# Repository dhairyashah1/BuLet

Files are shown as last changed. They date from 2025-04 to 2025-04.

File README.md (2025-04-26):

# BuLET: An Ultra Low Energy Transmitter

This repository contains the code and artifacts for **BuLet** which is developed as a part of CS5272: Embedded Software Design Course Project, Spring 2025 held at NUS.

> The BuLET system aims to enable low-power BLE
advertisement transmissions in the 1M / 2M PHY modes with
the provision of Extended PHY later. These transmissions are
decodable by commodity BLE receivers like smartphones:

<div align="center">
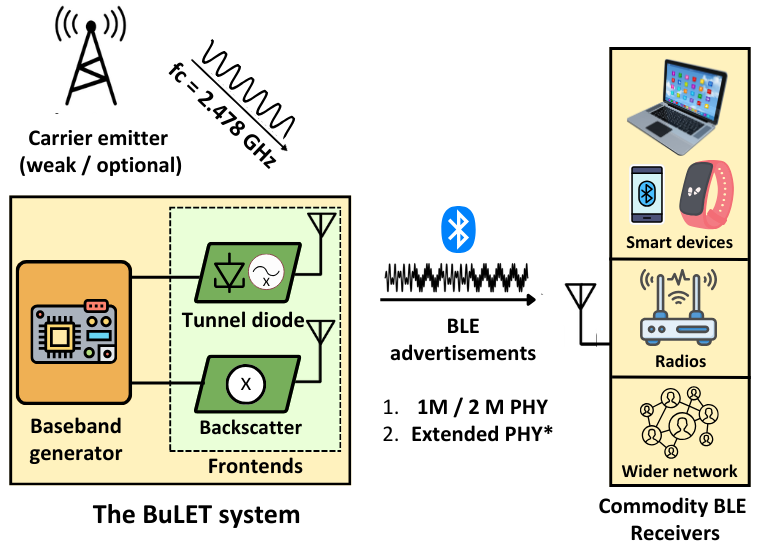
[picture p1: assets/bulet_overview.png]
BuLET Overview

</div>

## Abstract

Increased embedded system deployments have driven the widespread adoption of various wireless standards. Commonly used protocols include Wi-Fi, Bluetooth, ZigBee, and LoRa operate in the Industrial, Scientific and Medical bands (ISM) i.e. 868 MHz and 2.4 GHz showing their ubiquity and allowance for unlicensed transmissions. Despite advancements in low-power sensors and microcontrollers, the wireless radio subsystem—particularly its analog front end—remains a major power bottleneck in embedded IoT devices. Classic Bluetooth and Bluetooth Low Energy (BLE) dominate short-range wireless communication in the 2.4 GHz spectrum, with BLE favored for its energy efficiency in lightweight, battery-powered applications. However, even state-of-the-art BLE transmitters typically consume around 20 mW  to hundreds to milliwatts, limiting lifetime for battery-operated devices. Existing low-power solutions, such as BLE backscatter, decrease transmission power but rely on external emitters to generate carrier signals, which incurs additional energy costs. Tunnel diode oscillators present another option for generating radio signals with power consumption below 100 µW but face stability issues. In this work, we introduce BuLET, an ultra-low-power Bluetooth transmitter that integrate both backscatter and tunnel diode oscillator (TDO)-based frontends with a commercial microcontroller to generate BLE-compliant advertisements for unidirectional communication. We also demonstrate sub-harmonic injection locking to stabilize the TDO for reliable communication.

## Contributions

1.  BuLET is a compact (10cm x 5cm) system built using off-the-shelf components. It houses a low-power microcontroller for baseband generation and processing combining both **tunnel diode** based and **backscatter** frontends. This enables energy-efficient unidirectional BLE advertisments}= for sustainable communication.
2. Extending on Judo architecture, BuLET stabilizes the TDO from resonant frequency shifts by injection-locking lower-frequency sub-harmonic of TDO at **1.239 GHz** (**sub-harmonic injection locking**, min strength = 50 dBm). This supports the argument that lower-frequency signals are easier to generate from commodity devices. 
3. BuLET has a total power consumption of under **250 µW** which includes the baseband generator and frontends.
4. BuLET's transmissions are compatible to be received by commodity BLE receivers like smartphones and tablets.

## Repository Organization

```
├── LICENSE
├── README.md
├── assets                     # pictures, plots and images
│   ├── backscatter_frontend
│   ├── baseband_generator
│   └── tdo_frontend
├── data_logs                  # spectrum analyzer data
│   ├── cabled_spectrum
│   └── wireless_spectrum
├── examples
├── firmware                   # firmware implementations for BLE baseband
│   ├── beaglebone             # (1) beaglebone black implementation using PRU
│   └── ble_baseband_5969      # (2) msp430 implementation 
└── hardware                   # hardware PCB design files for BuLET designed in eagle
    ├── README.md             
    ├── backscatter_frontend
    ├── baseband_generator
    └── tdo_frontend
```

## Hardware Design

### Platform and Baseband Generator

The hardware platform prototype of the BuLET
system consists of a baseband generator and both backscatter
and tunnel diode based frontends to support low-power BLE
transmissions.

<div align="center">
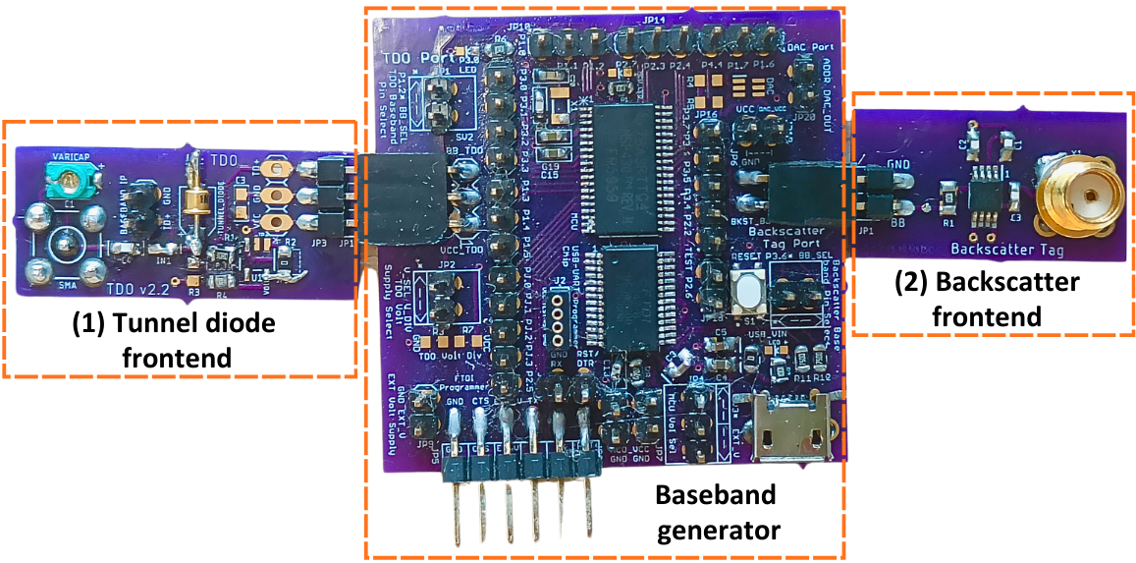
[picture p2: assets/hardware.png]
BuLET Hardware

</div>

### Tunnel Diode Oscillator Frontend

A tunnel diode oscillator built using a 1N3712 tunnel diode and passive RLC components. It oscillates at the following frequencies measured in a cabled setup.
- Principal frequency = 1.23 GHz, -26 dBm
- Second harmonic frequency = 2.47 GHz, -45 dBm

<div align="center">
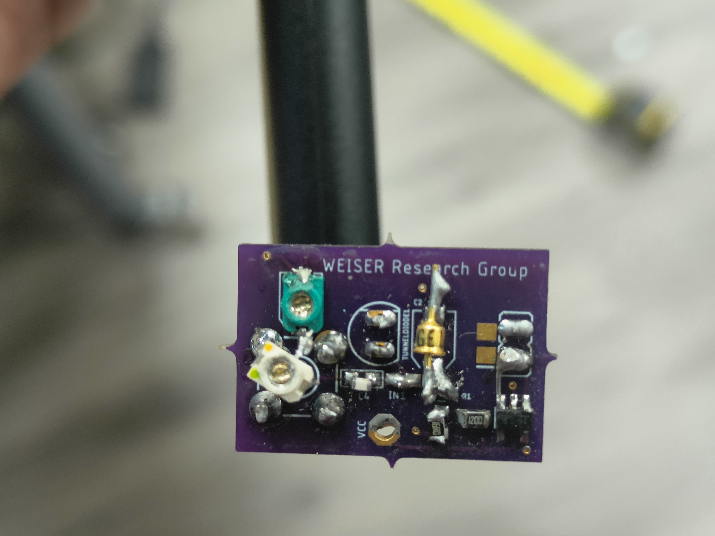
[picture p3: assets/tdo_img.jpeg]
TDO

</div>

Spectrum of unmodulated carrier signals generated by TDO captured in a cabled setup.

<div align="center">
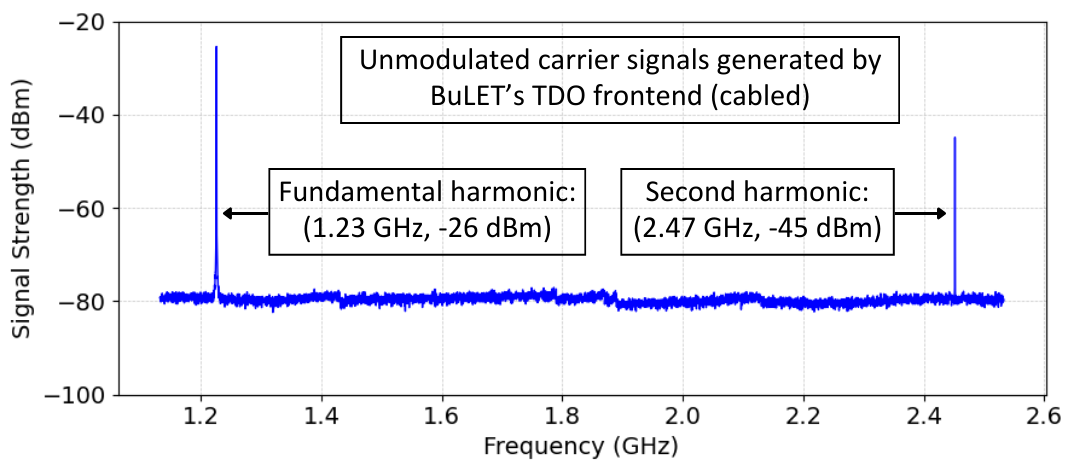
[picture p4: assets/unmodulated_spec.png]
Unmodulated spectrum of TDO

</div>

Spectrum of the modulated / mixed signal after sub-harmonic injection locking captured in a wireless setup. The carrier signals generated by TDO, after mixing with the BLE baseband signal represents the mixed signal. The lower-order or principal harmonic at 1.23 GHz is injection locked, which also stabilizes the second harmonic at 2.47 GHz. Minimum injection locking strength is reported to be as -50 dBm.

<div align="center">
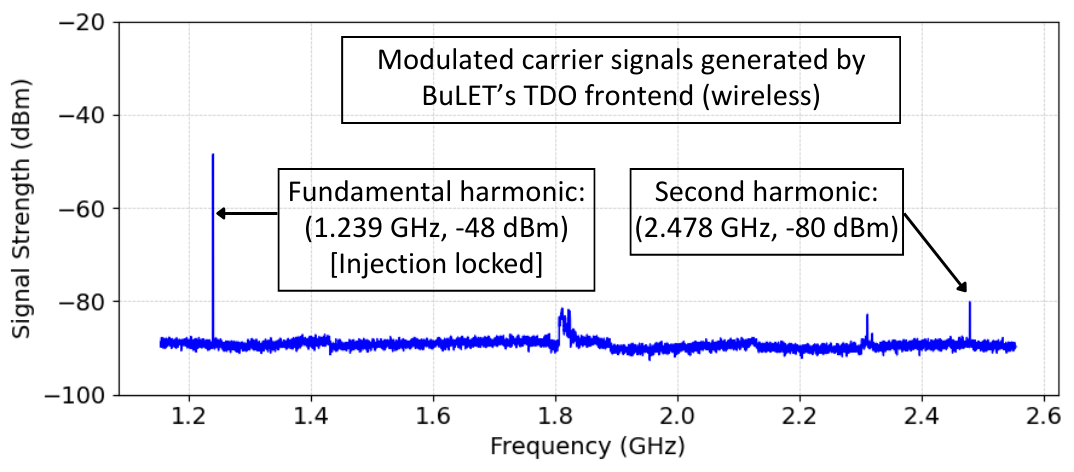
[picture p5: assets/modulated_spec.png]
Modulated spectrum of TDO

</div>

# Evaluation

### Evaluation Setup
<div align="center">
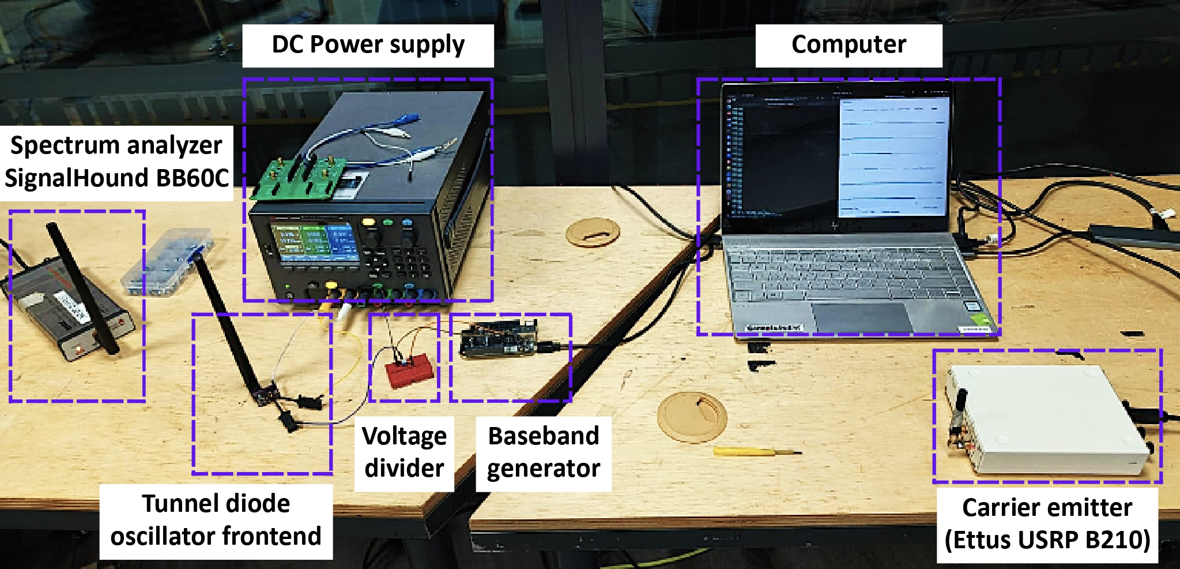
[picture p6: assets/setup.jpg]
Evaluation SEtup

</div>

### Backscatter Frontend

Signal strength of the BLE advertisements (mixed signal) recorded on a spectrum analyzer at various distances in a LoS setting with changing distances between the carrier emitter and the tag: 0.5 m, 1 m, 1.5 m, 2 m.

<div align="center">
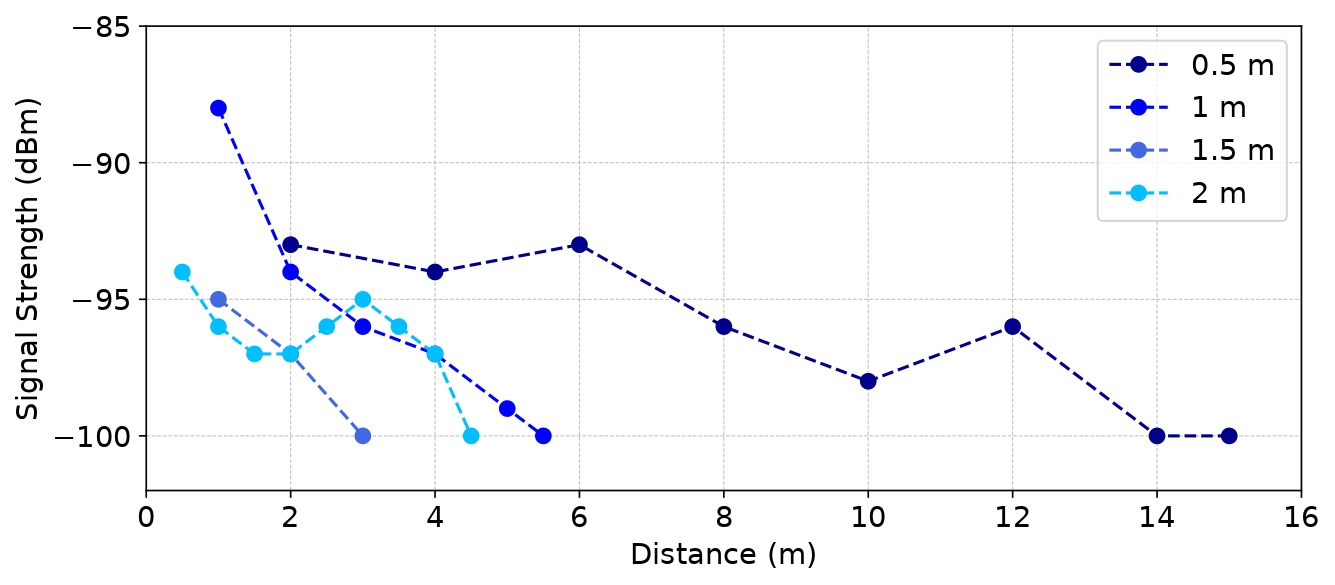
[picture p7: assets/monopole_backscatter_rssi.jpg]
Backscatter Evaluation

</div>

### Performance Comparison of Frontends

TDO frontend achieves a minimal range of 1 m as compared to 5.5 m by backscatter when the carrier emitter / injection locking device are kept each 1.5 m away from the tag. This is due to the weak carrier signal generated by TDO and even weaker mixed signal at 2.478 GHz (39th Advertisement channel).

<div align="center">
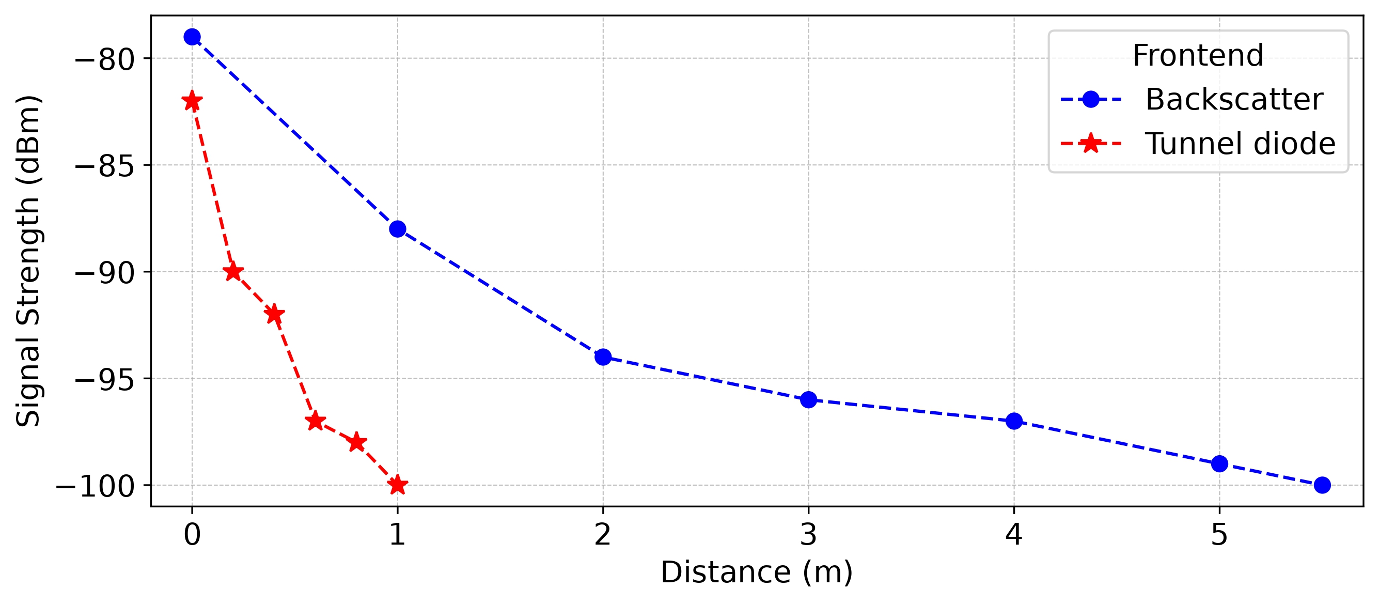
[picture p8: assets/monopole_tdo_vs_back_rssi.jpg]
Comparative Evaluation

</div>

### Reception

Successful reception of BuLET generated BLE advertisements from either frontends on a capable commodity smartphone.

<div align="center">
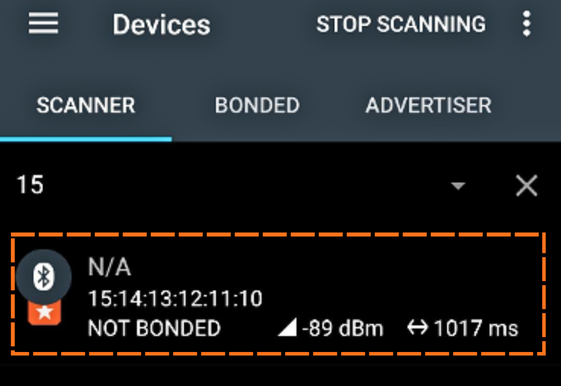
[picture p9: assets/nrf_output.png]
Output on smartphone

</div>

### Power consumption 

Comparison of power consumption and lifetime of BuLET with different wireless technologies on a 225 mAh CR2032 battery.

| **Technology** | **Power Consumption** | **Lifetime (225 mAh battery)** |
|:---|:---:|:---:|
| **Active Classic Bluetooth TX**  | 0.5 - 1 W | 40 minutes |
| **Active BLE TX** | 20 - 100 mW | 15 hours |
| **BuLET Backscatter TX** | 150 μW | 80 - 100 days |
| **BuLET Tunnel diode TX** | 250 μW | 50 - 80 days |

## Limitations

- Early prototype of a low-power BLE transmitter using tunnel diode oscillators (TDO) and sub-harmonic injection locking.
- Current TDO is unable to:
  - Generate stronger signal strength at the second harmonic. OR
  - Build a TDO operating with principal harmonic at 2.478 GHz.
- These limitations affect system performance and the ability to use weaker injection locking signals.
- Achieving this would establish significant novelty over existing backscatter systems.

## Future Work
- Build a 2.4 GHz TDO with a strong principal harmonic.
- Enable various BLE modes, including:
  - LE Coded PHY (Long Range Mode).
  - Frequency hopping on simple systems like BuLET.

## Acknowledgements

This project is completed and submitted to fulfill the requirements of CS5272: Embedded Software Design course at NUS (Spring 2025). I acknowledge and thank Prof. Ambuj Varshney for his support and guidance throughout this course.

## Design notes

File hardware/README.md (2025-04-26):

# Hardware Design Files

PCB Design Files for BuLET Platform - TDO | Backscatter Tag | MSP430 - Baseband Generator

These are designed using Eagle software. Please install it on your relevant Operating System.

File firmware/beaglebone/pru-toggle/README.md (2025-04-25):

## Installing Debian on the BBB ##

Use this version of Debian, others might not work:

https://debian.beagleboard.org/images/bone-debian-7.5-2014-05-14-2gb.img.xz

There may be some additional configuration necessary (disabling eMMC &
HDMI), but I'm not sure whether it's strictly necessary.

## Compiling the Device Tree Overlay ##

The device tree overlay activates the PRU and configures P8.11 as output
and P8.16 as input pins. You first need to compile the device tree
source into a binary blob:

    $ sudo dtc -O dtb -I dts -o /lib/firmware/PRU-GPIO-EXAMPLE-00A0.dtbo -b 0 -@ PRU-GPIO-EXAMPLE-00A0.dts

The blob then must be loaded:

    $ sudo -s
    # echo PRU-GPIO-EXAMPLE-00A0 > /sys/devices/bone_capemgr.?/slots                  #(This is old)
    # echo PRU-GPIO-EXAMPLE > /sys/devices/platform/bone_capemgr/slots           #(This is new)

Make sure that loading succeeded by looking at the output of dmesg

    # dmesg | tail
    [  636.923746] bone-capemgr bone_capemgr.9: part_number 'PRU-GPIO-EXAMPLE', version 'N/A'
    [  636.923926] bone-capemgr bone_capemgr.9: slot #7: generic override
    [  636.923972] bone-capemgr bone_capemgr.9: bone: Using override eeprom data at slot 7
    [  636.924021] bone-capemgr bone_capemgr.9: slot #7: 'Override Board Name,00A0,Override Manuf,PRU-GPIO-EXAMPLE'
    [  636.924290] bone-capemgr bone_capemgr.9: slot #7: Requesting part number/version based 'PRU-GPIO-EXAMPLE-00A0.dtbo
    [  636.924337] bone-capemgr bone_capemgr.9: slot #7: Requesting firmware 'PRU-GPIO-EXAMPLE-00A0.dtbo' for board-name 'Override Board Name',  version '00A0'
    [  637.020116] bone-capemgr bone_capemgr.9: slot #7: dtbo 'PRU-GPIO-EXAMPLE-00A0.dtbo' loaded; converting to live tree
    [  637.020570] bone-capemgr bone_capemgr.9: slot #7: #2 overlays
    [  637.040291] omap_hwmod: pruss: failed to hardreset
    [  637.067891] bone-capemgr bone_capemgr.9: slot #7: Applied #2 overlays.

## fsk ##

The fsk.[cp] programs use the PRU to toggle the GPIO pin P8.11 at
compile-time defined frequencies.

Modify fsk.c to write tuples of (ntoggles, delay) into the PRU's RAM.
Example:

    pruMem8[0] = 5;
    pruMem8[1] = DELAY(80);
    pruMem8[2] = 10;
    pruMem8[3] = DELAY(160);
    pruMem8[4] = 0; // Last byte must always be 0.

This will first toggle the GPIO five times with a delay of 80 ns in
between, and then toggle the GPIO ten times with a delay of 160 ns in
between.

The delay must be a multiple of 10 an must be at least 80 ns and at
most 2580 ns. `ntoggle` must be between 1 and 255.

To run:

    $ make fsk
    $ sudo ./fsk

## Useful resources ##

* http://credentiality2.blogspot.se/2015/09/beaglebone-pru-gpio-example.html
* http://mythopoeic.org/bbb-pru-minimal/
* https://github.com/beagleboard/am335x_pru_package

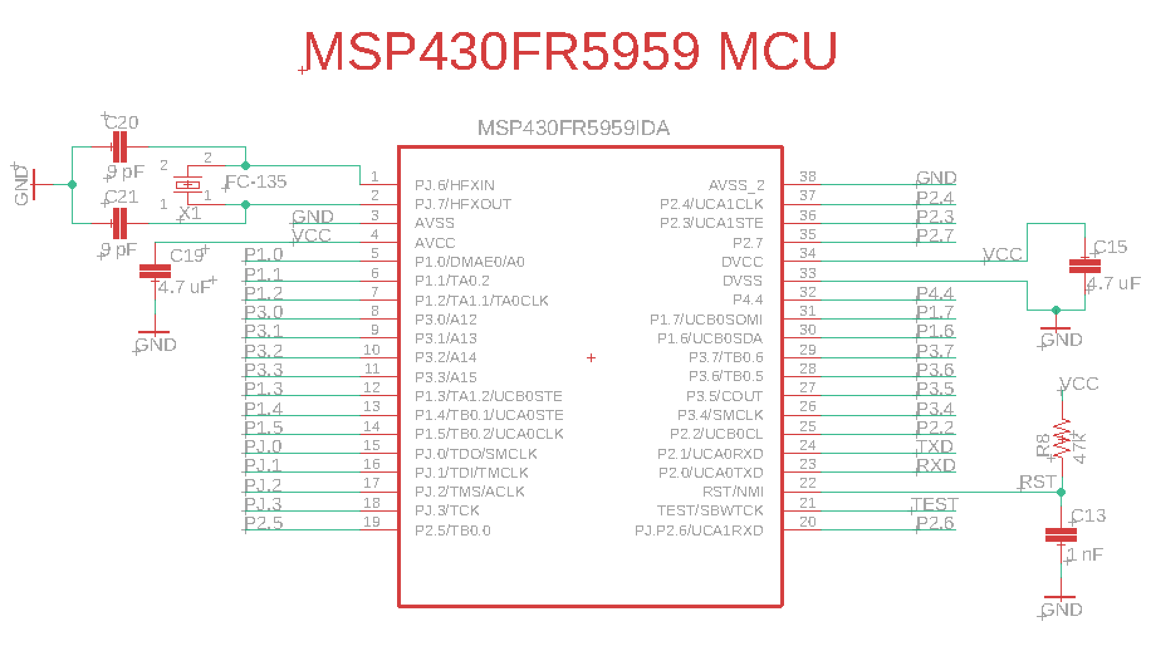
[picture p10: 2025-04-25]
assets/baseband_generator/MCU_schematic.png

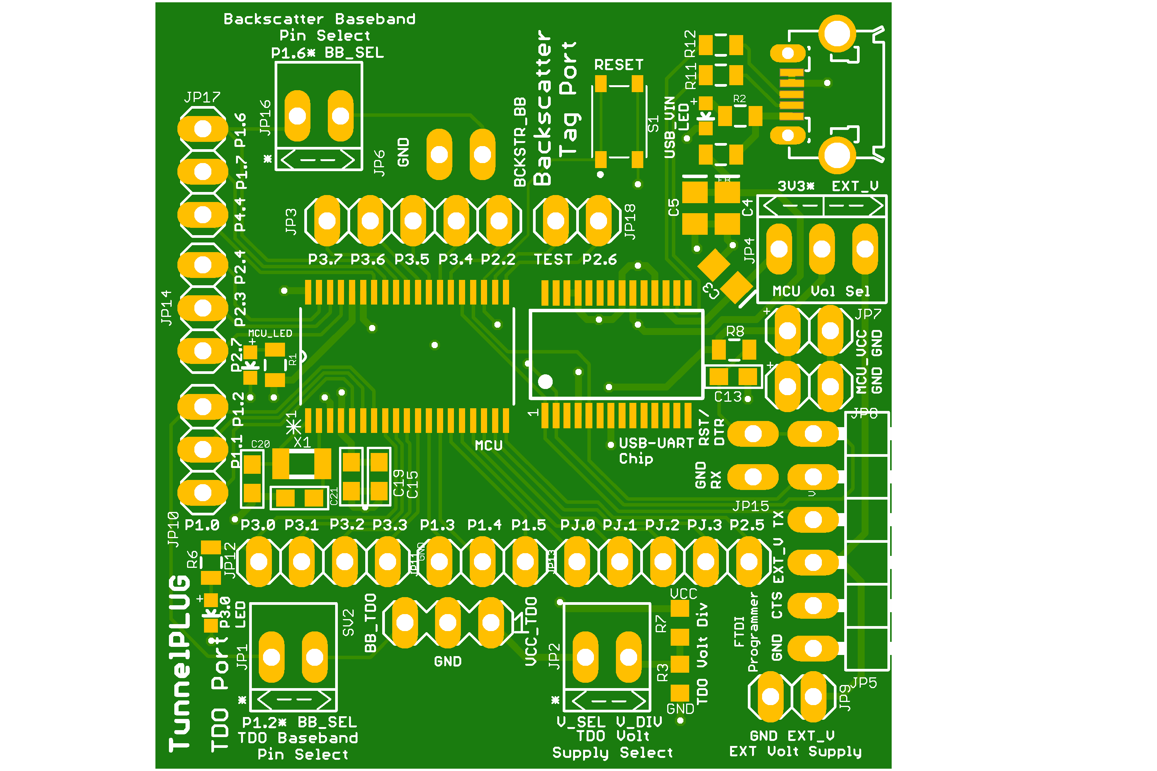
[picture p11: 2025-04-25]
assets/baseband_generator/bulet_layout.png

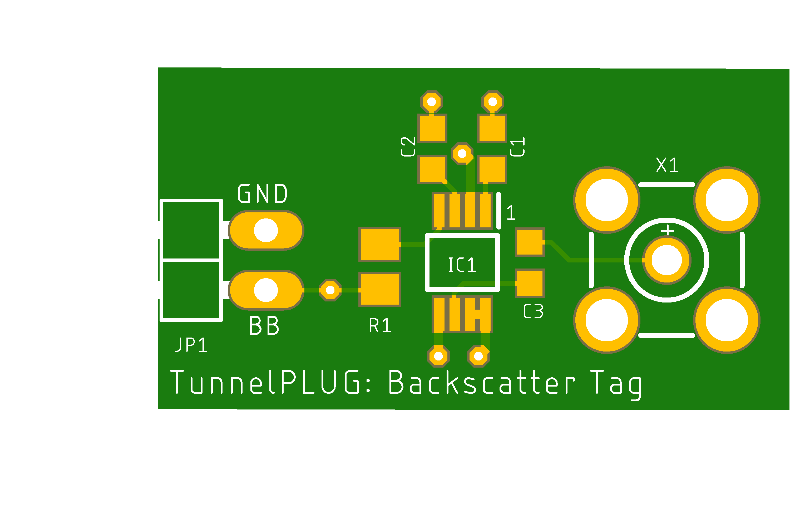
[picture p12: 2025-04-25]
assets/backscatter_frontend/backscatter_tag_layout.png

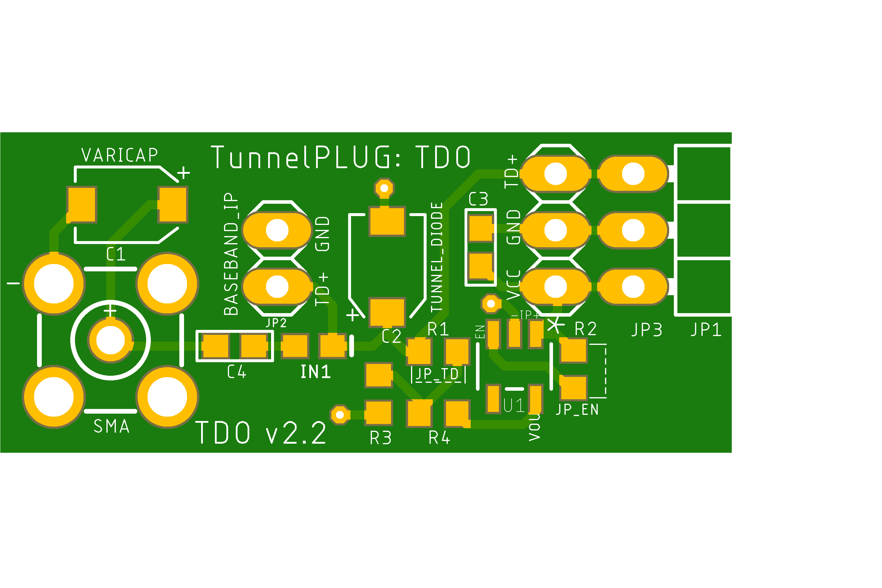
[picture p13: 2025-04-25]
assets/tdo_frontend/tdo_layout.png

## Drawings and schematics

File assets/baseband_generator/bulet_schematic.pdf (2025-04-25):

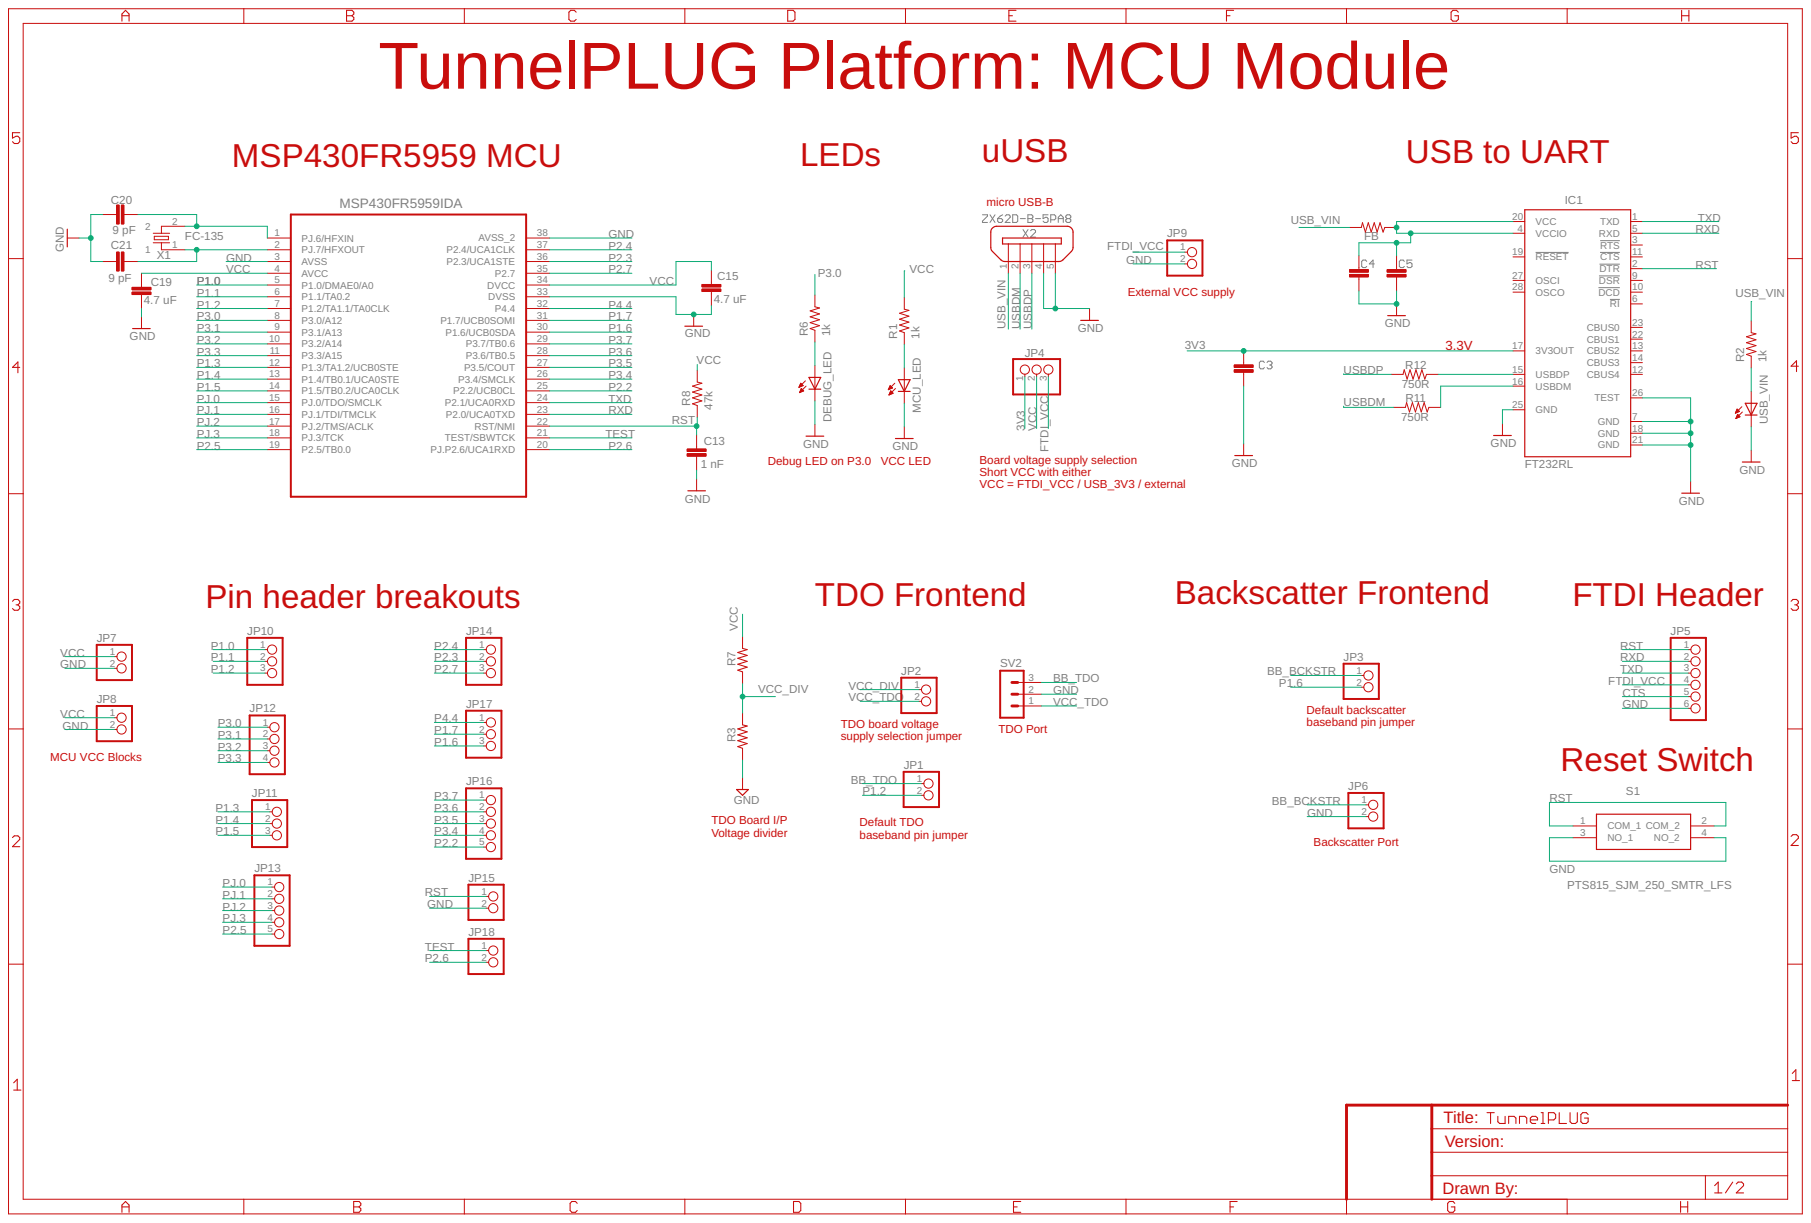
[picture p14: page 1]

TunnelPLUG Platform: MCU Module

VCC_TDO
Default backscatter baseband pin jumper Default TDO
TDO board voltage

GND
Backscatter Port TDO Board I/P

Drawn By: Title: Version:

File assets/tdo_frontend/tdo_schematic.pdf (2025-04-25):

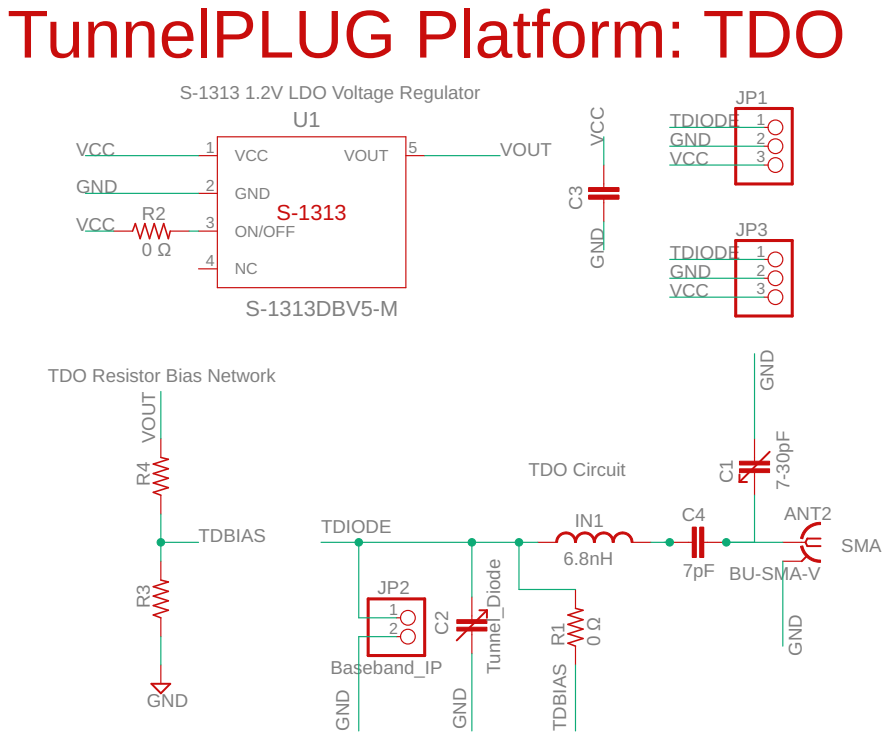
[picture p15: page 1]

TDO Resistor Bias Network

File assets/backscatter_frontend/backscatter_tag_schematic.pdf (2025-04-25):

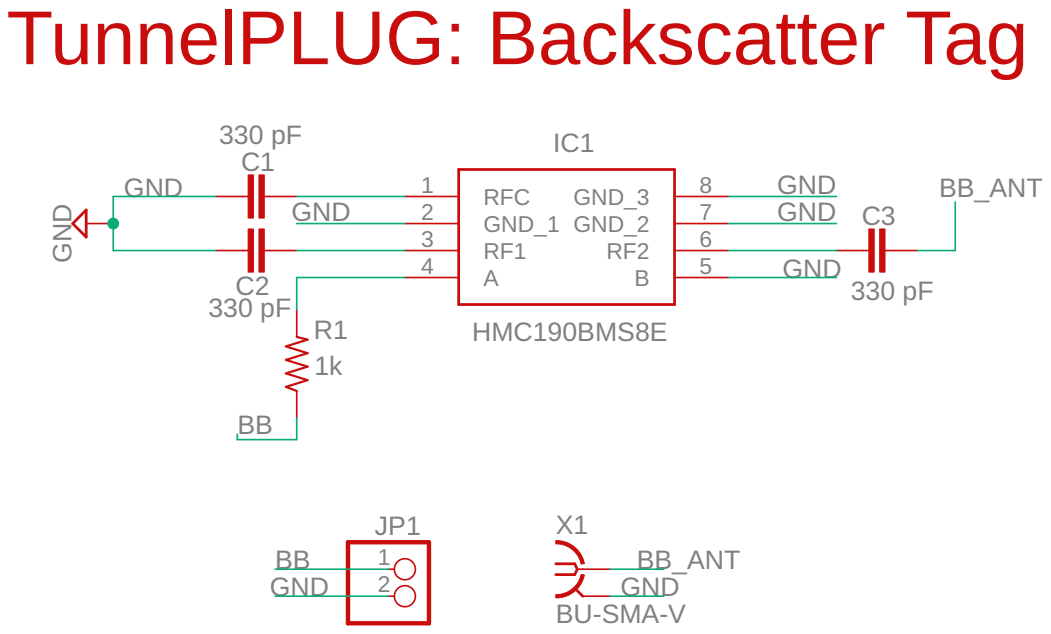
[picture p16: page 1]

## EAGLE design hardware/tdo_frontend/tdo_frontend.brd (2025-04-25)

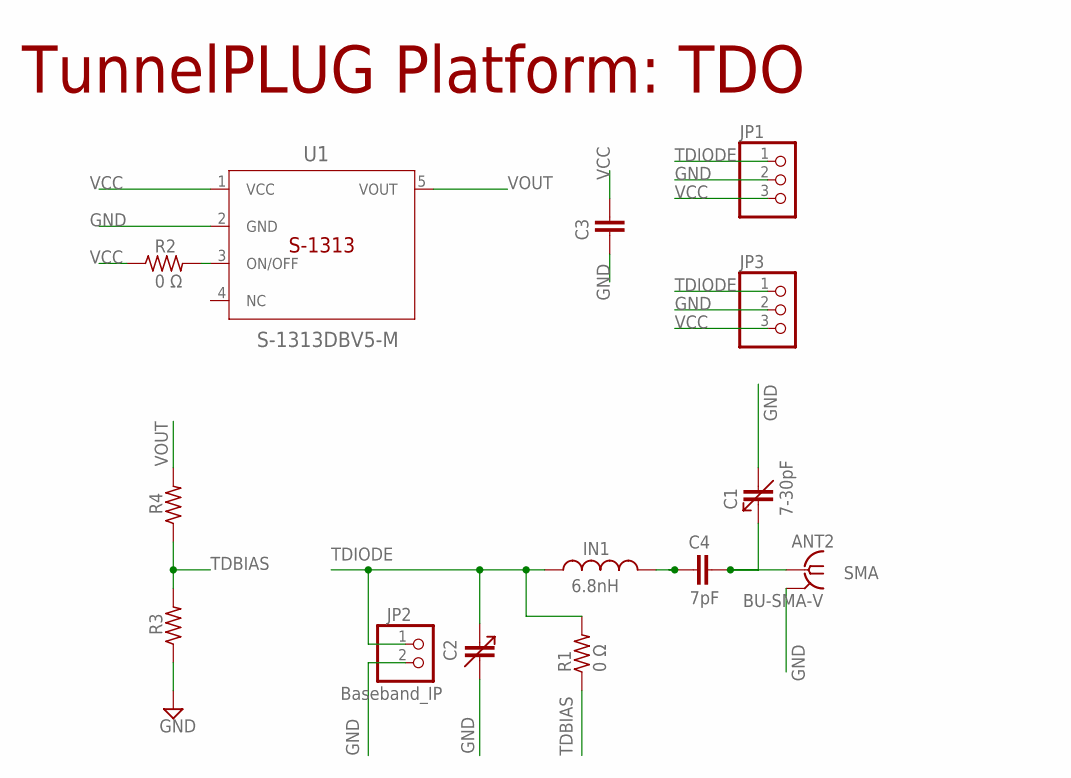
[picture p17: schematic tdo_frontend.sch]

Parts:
C1, C2: 7-30pF; CTZ3
C3: CAPACITOR; C0603
C4: 7pF; C0603
IN1: 6.8nH; 0603_1PRIMARY
JP1: PINHD-1X3/90; 1X03/90
JP2: Baseband_IP; 1X02
JP3: PINHD-1X3/LONG; 1X03
R1, R2: 0 Ω; R0603
R3, R4: R-US_R0603; R0603
SMA: BU-SMA-V
U1: S-1313DBV5-M; DBV5-M

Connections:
ANT2: C1.+ (3), C4.2, SMA.1
GND: C1.- (4), C2.- (4), C3.1, JP1.2, JP2.2, JP3.2, R3.1, SMA.2, SMA.3 (2), SMA.4 (2), SMA.5 (2), U1.2 (GND)
unnamed: R2.2, U1.3 (ON/OFF)
unnamed: C4.1, IN1.2
TDBIAS: R1.1, R3.2, R4.1
TDIODE: C2.+ (3), IN1.1, JP1.1, JP2.1, JP3.1, R1.2
VCC: C3.2, JP1.3, JP3.3, R2.1, U1.1 (VCC)
VOUT: R4.2, U1.5 (VOUT)

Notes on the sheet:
TunnelPLUG Platform: TDO

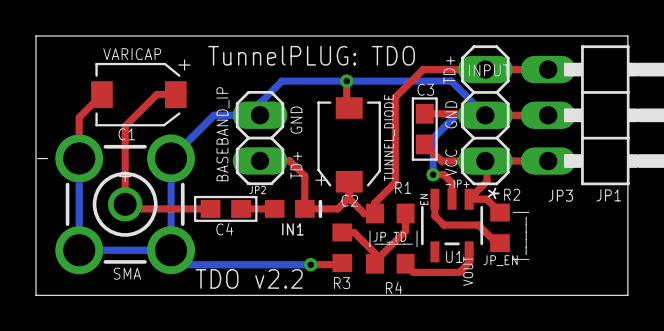
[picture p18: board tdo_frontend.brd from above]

Board: 2 copper layers, 32.9 x 14.4 mm, 14 parts (0 on the bottom side), 8 nets.

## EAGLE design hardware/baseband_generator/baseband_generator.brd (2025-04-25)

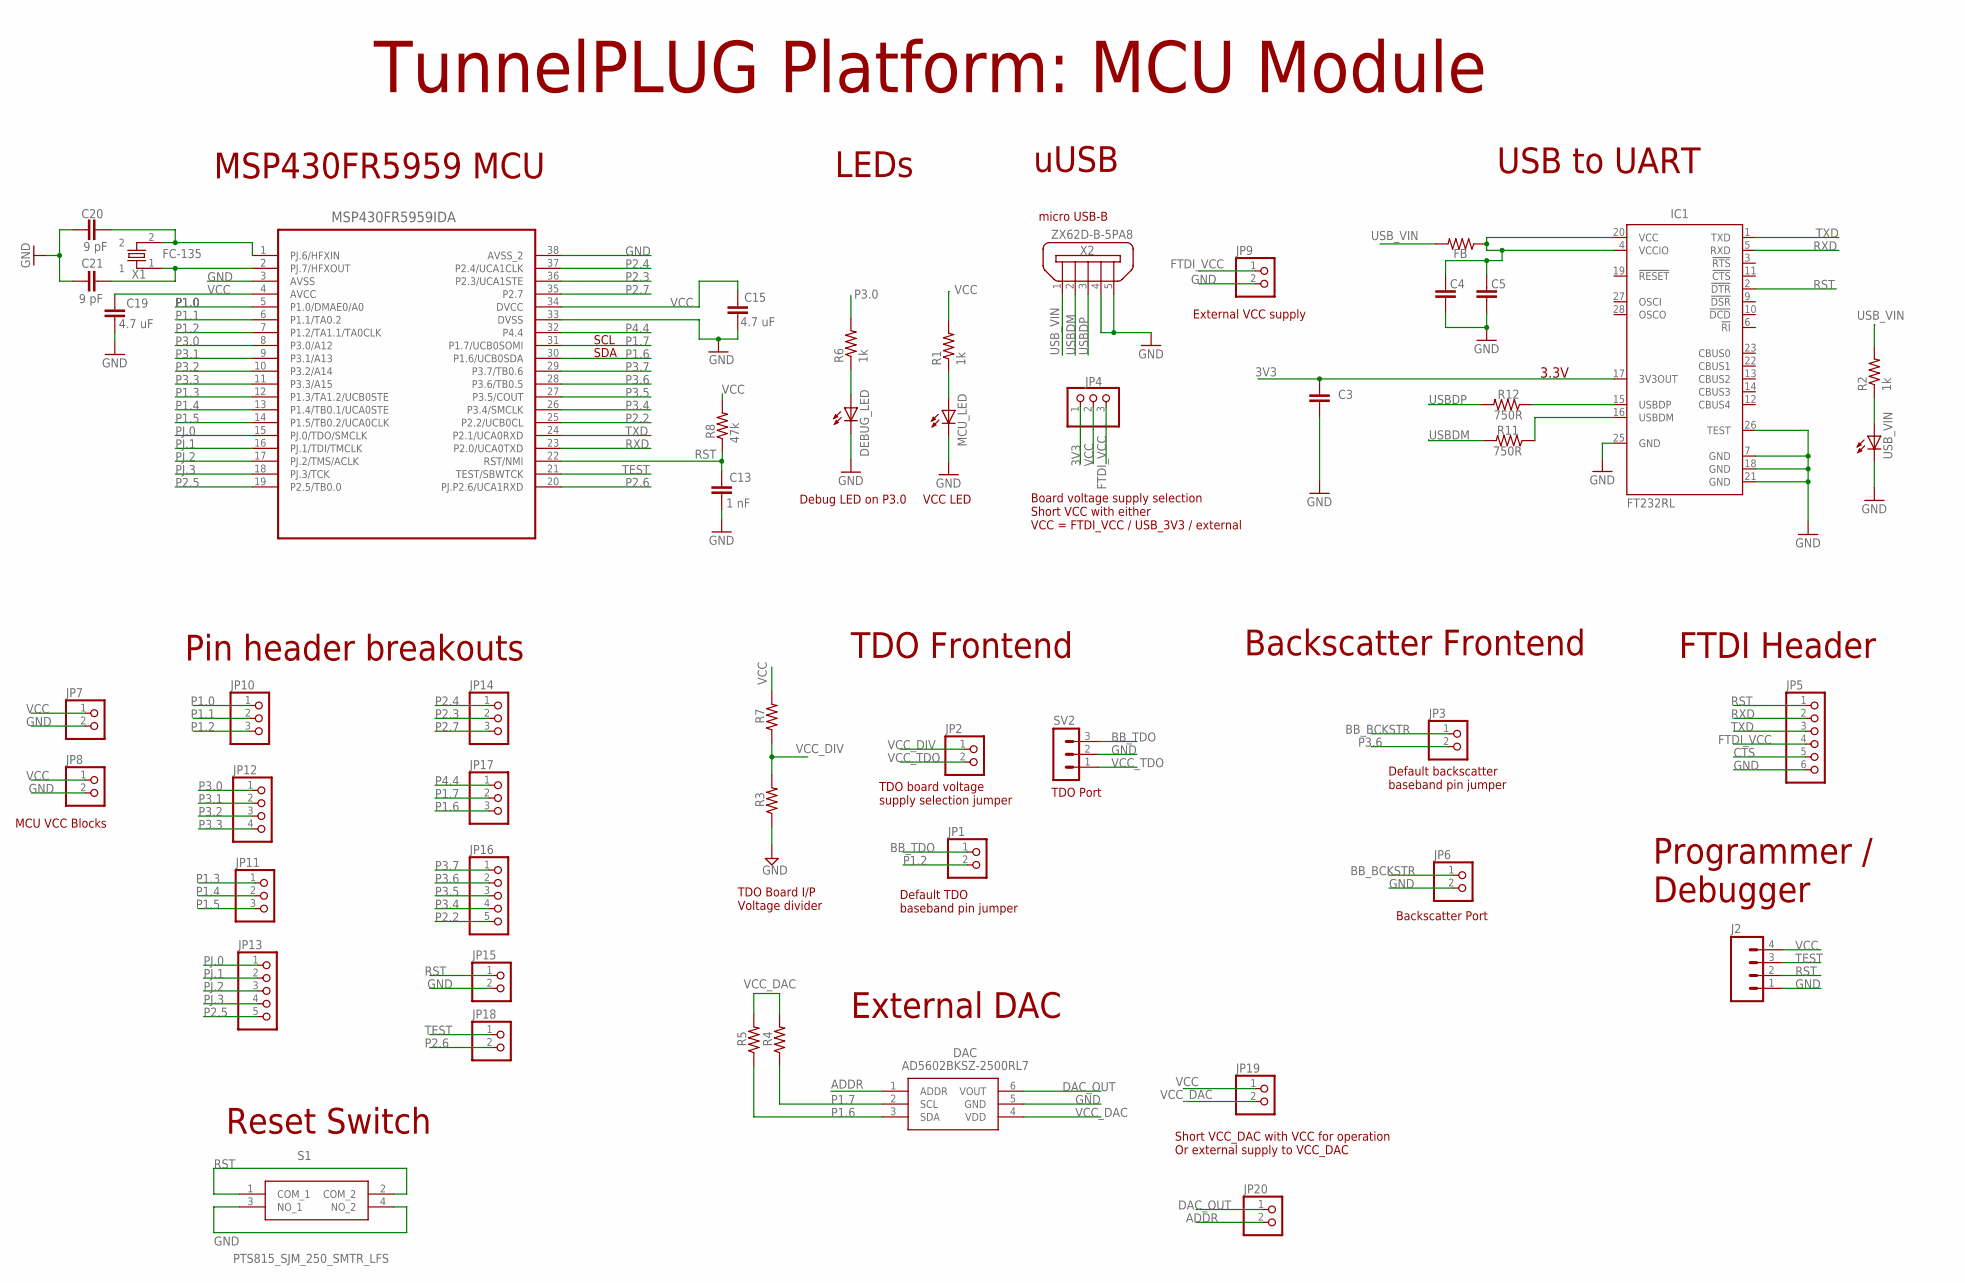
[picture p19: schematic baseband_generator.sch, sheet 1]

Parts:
C3, C4, C5: 0805_1; 0805_1PRIMARY
C13: 1 nF; C0603
C15, C19: 4.7 uF; C0603
C20, C21: 9 pF; C0603
DAC: AD5602BKSZ-2500RL7; SOT65P210X110-6N
DEBUG_LED: LED0603; LED-0603
FB: RESISTOR0805-RES; 0805
IC1: FT232RL; SSOP28
J2: MHDR1X4_1; MHDR1X4_1PRIMARY
JP1, JP2, JP3: PINHD-1X2/LOCK; 1X02/LOCK
JP4: PINHD-1X3/LOCK; 1X03/LOCK
JP5: PINHD-1X6/90; 1X06/90
JP6, JP7, JP8, JP9, JP15, JP18, JP19, JP20: PINHD-1X2; 1X02
JP10, JP11, JP14, JP17: PINHD-1X3; 1X03
JP12: PINHD-1X4; 1X04
JP13, JP16: PINHD-1X5; 1X05
MCU_LED: LED0603; LED-0603
R1, R2, R6: 1k; 0805
R3, R4, R5, R7: R-US_R0603; R0603
R8: 47k; 0805
R11, R12: 750R; 0805
S1: PTS815_SJM_250_SMTR_LFS; PTS815SJM250SMTRLFS
SV2: MA03-1
U2: MSP430FR5739IDAMSP430FR5959IDA; SOP65P810X120-38N
USB_VIN: LED0603; LED-0603
X1: FC-135; FC-135_1PRIMARY
X2: ZX62D-B-5PA8

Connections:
3V3: C3.1, IC1.17 (3V3OUT), JP4.1
ADDR: DAC.1 (ADDR), JP20.2
BB_BCKSTR: JP3.1, JP6.1
BB_TDO: JP1.1, SV2.3
CTS: JP5.5
DAC_OUT: DAC.6 (VOUT), JP20.1
FTDI_VCC: JP4.3, JP5.4, JP9.1
GND: C3.2, C4.2, C5.2, C13.2, C15.1, C19.2, C20.2, C21.2, DAC.5 (GND), DEBUG_LED.C, IC1.7 (GND), IC1.18 (GND), IC1.21 (GND), IC1.25 (GND), IC1.26 (TEST), J2.1, JP5.6, JP6.2, JP7.2, JP8.2, JP9.2, JP15.2, MCU_LED.C, R3.1, S1.3 (NO_1), S1.4 (NO_2), SV2.2, U2.3 (AVSS), U2.33 (DVSS), U2.38 (AVSS_2), USB_VIN.C, X2.4, X2.5
unnamed: C21.1, U2.2 (PJ.7/HFXOUT), X1.1
unnamed: C20.1, U2.1 (PJ.6/HFXIN), X1.2
unnamed: DEBUG_LED.A, R6.1
unnamed: MCU_LED.A, R1.1
unnamed: R2.1, USB_VIN.A
unnamed: C4.1, C5.1, FB.1, IC1.4 (VCCIO), IC1.20 (VCC)
unnamed: IC1.15 (USBDP), R12.1
unnamed: IC1.16 (USBDM), R11.1
P1.0: JP10.1, U2.5 (P1.0/DMAE0/A0)
P1.1: JP10.2, U2.6 (P1.1/TA0.2)
P1.2: JP1.2, JP10.3, U2.7 (P1.2/TA1.1/TA0CLK)
P1.3: JP11.1, U2.12 (P1.3/TA1.2/UCB0STE)
P1.4: JP11.2, U2.13 (P1.4/TB0.1/UCA0STE)
P1.5: JP11.3, U2.14 (P1.5/TB0.2/UCA0CLK)
P1.6: DAC.3 (SDA), JP17.3, R5.1, U2.30 (P1.6/UCB0SDA)
P1.7: DAC.2 (SCL), JP17.2, R4.1, U2.31 (P1.7/UCB0SOMI)
P2.2: JP16.5, U2.25 (P2.2/UCB0CL)
P2.3: JP14.2, U2.36 (P2.3/UCA1STE)
P2.4: JP14.1, U2.37 (P2.4/UCA1CLK)
P2.5: JP13.5, U2.19 (P2.5/TB0.0)
P2.6: JP18.2, U2.20 (PJ.P2.6/UCA1RXD)
P2.7: JP14.3, U2.35 (P2.7)
P3.0: JP12.1, R6.2, U2.8 (P3.0/A12)
P3.1: JP12.2, U2.9 (P3.1/A13)
P3.2: JP12.3, U2.10 (P3.2/A14)
P3.3: JP12.4, U2.11 (P3.3/A15)
P3.4: JP16.4, U2.26 (P3.4/SMCLK)
P3.5: JP16.3, U2.27 (P3.5/COUT)
P3.6: JP3.2, JP16.2, U2.28 (P3.6/TB0.5)
P3.7: JP16.1, U2.29 (P3.7/TB0.6)
P4.4: JP17.1, U2.32 (P4.4)
PJ.0: JP13.1, U2.15 (PJ.0/TDO/SMCLK)
PJ.1: JP13.2, U2.16 (PJ.1/TDI/TMCLK)
PJ.2: JP13.3, U2.17 (PJ.2/TMS/ACLK)
PJ.3: JP13.4, U2.18 (PJ.3/TCK)
RST: C13.1, IC1.2 (!DTR), J2.2, JP5.1, JP15.1, R8.1, S1.1 (COM_1), S1.2 (COM_2), U2.22 (RST/NMI)
RXD: IC1.5 (RXD), JP5.2, U2.23 (P2.0/UCA0TXD)
TEST: J2.3, JP18.1, U2.21 (TEST/SBWTCK)
TXD: IC1.1 (TXD), JP5.3, U2.24 (P2.1/UCA0RXD)
USBDM: R11.2, X2.2
USBDP: R12.2, X2.3
USB_VIN: FB.2, R2.2, X2.1
VCC: C15.2, C19.1, J2.4, JP4.2, JP7.1, JP8.1, JP19.1, R1.2, R7.2, R8.2, U2.4 (AVCC), U2.34 (DVCC)
VCC_DAC: DAC.4 (VDD), JP19.2, R4.2, R5.2
VCC_DIV: JP2.1, R3.2, R7.1
VCC_TDO: JP2.2, SV2.1

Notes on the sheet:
MSP430FR5959 MCU
LEDs
TunnelPLUG Platform: MCU Module
uUSB
USB to UART
FTDI Header
3.3V
Board voltage supply selection Short VCC with either VCC = FTDI_VCC / USB_3V3 / external
TDO Frontend
Backscatter Frontend
Debug LED on P3.0
micro USB-B
VCC LED
Pin header breakouts
External VCC supply
Default backscatter baseband pin jumper
Default TDO baseband pin jumper
TDO board voltage supply selection jumper
TDO Port
Backscatter Port
TDO Board I/P Voltage divider
MCU VCC Blocks
Reset Switch
External DAC
Short VCC_DAC with VCC for operation Or external supply to VCC_DAC
SCL
SDA
Programmer / Debugger

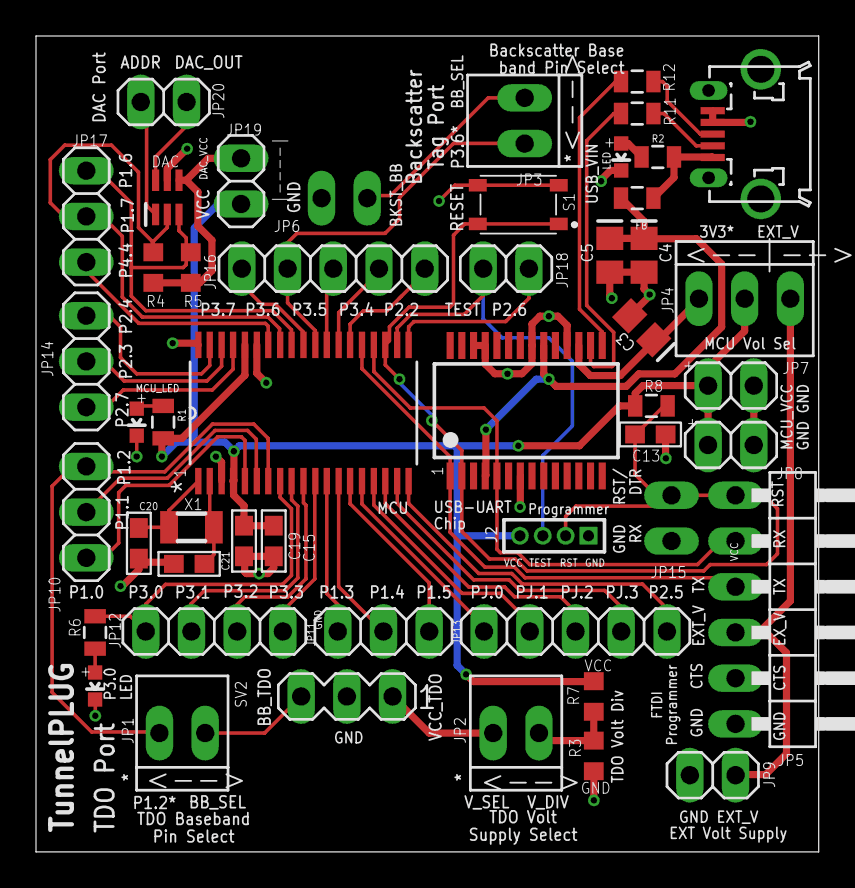
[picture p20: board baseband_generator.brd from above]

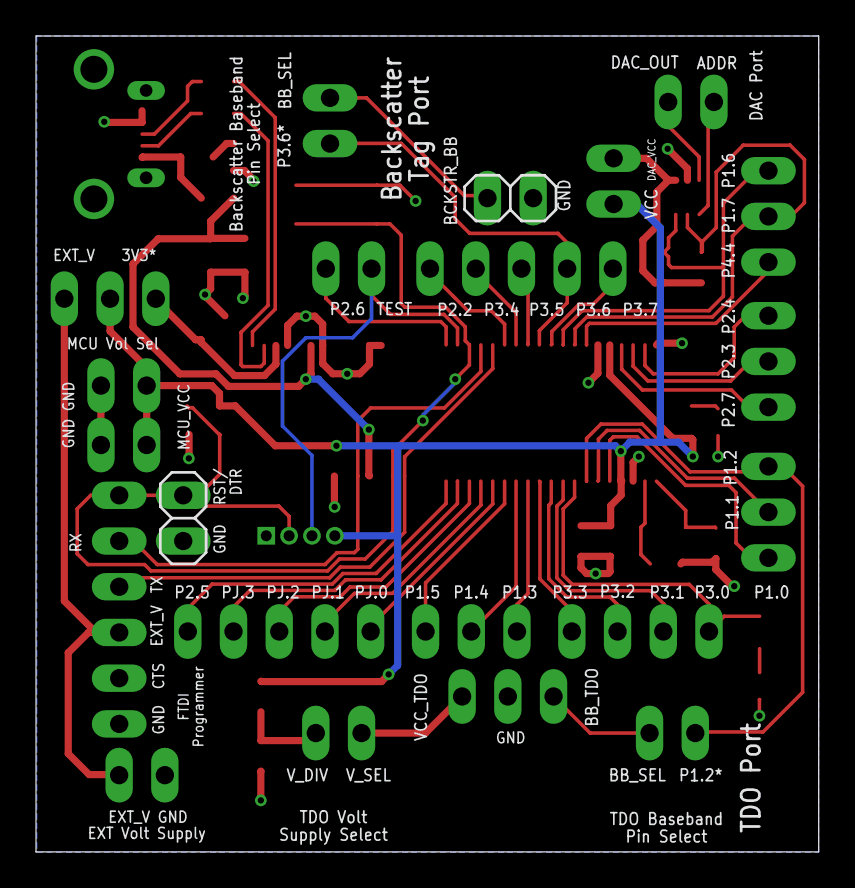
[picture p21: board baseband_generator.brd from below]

Board: 2 copper layers, 43.5 x 45.3 mm, 50 parts (2 on the bottom side), 53 nets.

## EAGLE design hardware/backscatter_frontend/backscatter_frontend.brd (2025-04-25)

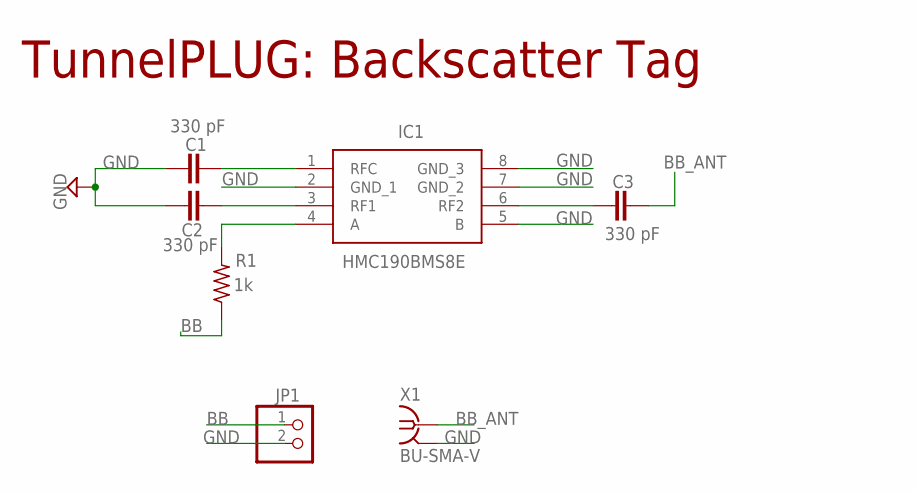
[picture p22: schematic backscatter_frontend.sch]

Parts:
C1, C2, C3: 330 pF; C0603K
IC1: HMC190BMS8E; SOP65P488X110-8N
JP1: PINHD-1X2/L90; 1X02/90
R1: 1k; M0805
X1: BU-SMA-V

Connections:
BB: JP1.1, R1.1
BB_ANT: C3.2, X1.1
GND: C1.1, C2.1, IC1.2 (GND_1), IC1.5 (B), IC1.7 (GND_2), IC1.8 (GND_3), JP1.2, X1.2, X1.3 (2), X1.4 (2), X1.5 (2)
unnamed: C1.2, IC1.1 (RFC)
unnamed: C2.2, IC1.3 (RF1)
unnamed: IC1.4 (A), R1.2
unnamed: C3.1, IC1.6 (RF2)

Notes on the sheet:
TunnelPLUG: Backscatter Tag

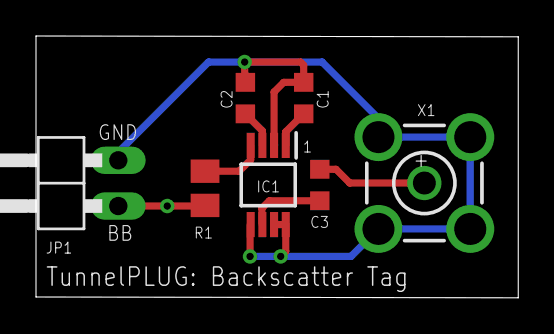
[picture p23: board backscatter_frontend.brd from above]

Board: 2 copper layers, 26.8 x 14.5 mm, 7 parts (0 on the bottom side), 7 nets.

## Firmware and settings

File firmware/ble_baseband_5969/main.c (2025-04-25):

// BLE baseband implementation

#include <msp430fr5969.h>
#include <stdint.h>
#include <stddef.h>
#include <stdio.h>
#include <stdlib.h>
#include <string.h>

#include "blebs_base.h"

// Define which pin will output our signal (using Timer output)
#define BLE_OUTPUT_PIN BIT2  // Using P1.2 (Timer0_A2 output)
#define TIMER_CC_REG TA0CCR2  // Using CCR2 for output

uint8_t   blePacket1[] = {
                         /* Preamble */
                         0xAA,

                         /* Access Address */
                         0xD6, 0xBE, 0x89, 0x8E,

                         /* Header */
                         0x42, //ADV_NONCONN_IND, random address
                         19, //len byte

                         /* Address */
                         0xEF, 0xFF, 0xC0, 0xAA, 0x18, 0x00,

                         /* Advertising data: Flags AD Type */
                         0x02, //len byte
                         0x01, //AD type = flag
                         0x06, //LE General Discoverable Mode,BR/EDR Not Supported

                         /* Advertising data: Complete Local Name */
                         9, //len byte
                         0x08, //AD type = Shortened local name
                         'I','O','E',' ','c','h','3', '7',

                         /* CRC */
                         0x55, 0x55, 0x55 //initial crc lfsr
};

uint8_t   blePacket2[] = {
                         /* Preamble */
                         0xAA,

                         /* Access Address */
                         0xD6, 0xBE, 0x89, 0x8E,

                         /* Header */
                         0x42, //ADV_NONCONN_IND, random address
                         19, //len byte

                         /* Address */
                         0xEF, 0xFF, 0xC0, 0xAA, 0x18, 0x01,

                         /* Advertising data: Flags AD Type */
                         0x02, //len byte
                         0x01, //AD type = flag
                         0x06, //LE General Discoverable Mode,BR/EDR Not Supported

                         /* Advertising data: Complete Local Name */
                         9, //len byte
                         0x08, //AD type = Shortened local name
                         'I','O','E',' ','c','h','3', '8',
                         //'I', 'L', 'V', 'E', 'E',

                         /* CRC */
                         0x55, 0x55, 0x55 //initial crc lfsr
};

uint8_t blePacket0[] = {
                            0xAA, 0xAA, 0xAA, 0xAA,
                            0xAA, 0xAA, 0xAA, 0xAA,
                            0xAA, 0xAA, 0xAA, 0xAA,
                            0xAA, 0xAA, 0xAA, 0xAA,
                            0xAA, 0xAA, 0xAA, 0xAA,
                            0xAA, 0xAA, 0xAA, 0xAA,
                            0xAA, 0xAA, 0xAA, 0xA5,
        };

uint8_t dmaBuff[8 * sizeof(blePacket1)];

uint8_t*  ptr_blePacket;
uint8_t   len_blePacket;

/**
 * swapbit
 */
uint8_t  swapbits(uint8_t byte)
{
    uint8_t ret = 0;

    if(byte & 0x80) ret |= 0x01;
    if(byte & 0x40) ret |= 0x02;
    if(byte & 0x20) ret |= 0x04;
    if(byte & 0x10) ret |= 0x08;
    if(byte & 0x08) ret |= 0x10;
    if(byte & 0x04) ret |= 0x20;
    if(byte & 0x02) ret |= 0x40;
    if(byte & 0x01) ret |= 0x80;

    return ret;
}

/**
 * bleWhiten
 */
void bleWhiten(uint8_t* data, uint8_t len, uint8_t chan){

    uint8_t  bit, lfsr = swapbits(chan) | 2;

    while(len--)
    {
        for(bit = 0x80; bit; bit >>= 1){

            if(lfsr & 0x80){

                lfsr ^= 0x11;
                (*data) ^= bit;
            }
            lfsr <<= 1;
        }
        data++;
    }
}

/**
 * crc24_gen
 */
void crc24_gen(uint8_t* data, uint8_t len, uint8_t* dst)
{
    uint8_t i, bit, byte;

    while(len--)
    {
        byte = *data++;
        for(i = 0; i < 8; i++, byte <<= 1)
        {
            bit = dst[0] & 0x80;
            dst[0] <<= 1;
            if(dst[1] & 0x80) dst[0] |= 1;
            dst[1] <<= 1;
            if(dst[2] & 0x80) dst[1] |= 1;
            dst[2] <<= 1;

            if(bit != (byte & 0x80))  //Compare MSB of crc & LSB of pdu
            {
                dst[2] ^= 0x5B;
                dst[1] ^= 0x06;
            }
        }
    }
}

/**
 * BlePacketEncode
 */
void BlePacketEncode(uint8_t* packet, uint8_t len, uint8_t chan)
{
    uint8_t i;

    for(i = 0; i < len - 3; i++)
        packet[i] = swapbits(packet[i]);
    crc24_gen(packet + 5, len - 8, packet + len - 3);         //crc24_gen(pduStart, pduLength , crcStart)
    bleWhiten(packet + 5, len - 5, chan);                     //bleWhiten(pduStart, (pdu+crc)Length, channelCoefficient)
}

/**
 * void BLEBS_init(void)
 */
void BLEBS_init(void)
{

    WDTCTL = WDTPW | WDTHOLD;   // Stop watchdog timer

    // Disable FRAM wait cycles to allow clock operation over 8MHz
    FRCTL0 = 0xA500 | ((1) << 4);  //FRCTLPW | NWAITS_1;

    //Init GPIO
    P1OUT = BIT1;                             // Pull-up resistor on P1.1
    P1REN = BIT1;                             // Select pull-up mode for P1.1
    P1DIR = 0xFF ^ BIT1;                      // Set all but P1.1 to output direction
    P1SEL0 |= BIT3 | BIT4;                    // P1.3 and P1.4 options select
    P1IES = BIT1;                             // P1.1 Hi/Lo edge
    P1IFG = 0;                                // Clear all P1 interrupt flags
    P1IE = BIT1;                              // P1.1 interrupt enabled
    P2OUT = 0x00;
    P2DIR = 0xFF;
    //P2SEL1 |= BIT0 | BIT1;                    // USCI_A0 UART operation
    //P2SEL0 &= ~(BIT0 | BIT1);
    P3OUT = 0x00;
    P3DIR = 0xFF;
    //P3SEL1 |= BIT4;                           // P3.4 SMCLK
    P4OUT = 0x00;
    P4DIR = 0xFF;
    PJOUT = 0x00;
    PJDIR = 0xFF;
    //PJSEL0 |= BIT6 | BIT7;                    // For XT2

    // Init GPIO - Configure P1.2 for Timer output /////////////////////////////////////////////////////////
   P1DIR |= BLE_OUTPUT_PIN;     // Set P1.2 as output
   P1SEL0 |= BLE_OUTPUT_PIN;    // Set P1.2 to peripheral function (Timer output)
   P1SEL1 &= ~BLE_OUTPUT_PIN;   // Select Timer function

   // Init GPIO - Configure P1.2 for Timer output
//   P1DIR |= BLE_OUTPUT_PIN;     // Set P1.2 as output
//   P1SEL0 |= BLE_OUTPUT_PIN;    // Set P1.2 to peripheral function (Timer output)
//   P1SEL1 &= ~BLE_OUTPUT_PIN;   // Select Timer function
   /////////////////////////////////////////////////////////////////////////////////////////////////

    // Disable the GPIO power-on default high-impedance mode to activate previously configured port settings.
    PM5CTL0 &= ~LOCKLPM5;       // Lock LPM5.


    CSCTL0_H = 0xA5;
    CSCTL1 = DCORSEL | DCOFSEL_4; //16MHz
    CSCTL2 = SELA__VLOCLK | SELS__DCOCLK | SELM__DCOCLK;
    CSCTL3 = DIVA_0 | DIVS_0 | DIVM_0;
    CSCTL0_H = 0x00;

}

///////////////////////////////////////////////////////
void sendBit(uint8_t bit) {
    if (bit) {
        // For '1': Higher frequency (e.g., 2.25MHz)
        TA0CCR0 = 7;  // 16MHz/8 = 2MHz (example)
    } else {
        // For '0': Lower frequency (e.g., 1.78MHz)
        TA0CCR0 = 9;  // 16MHz/10 = 1.6MHz (example)
    }
    __delay_cycles(100);  // Hold for symbol duration
}

void sendBLEPacket() {
    uint8_t i, j;
    for (i = 0; i < len_blePacket; i++) {
        uint8_t byte = ptr_blePacket[i];
        for (j = 0; j < 8; j++) {
            sendBit((byte >> (7-j)) & 0x01);  // Send MSB first
        }
    }
}
////////////////////////////////////////////////////

/**
 * gpioSendBle
 */
void gpioSendBle(void)
{
    ptr_blePacket = blePacket1;
    len_blePacket = sizeof(blePacket1);
    sendBLEPacket();
    __delay_cycles(800000);
    ptr_blePacket = blePacket2;
    len_blePacket = sizeof(blePacket2);
    sendBLEPacket();
    __delay_cycles(800000);
}


/**
 * main.c
 */
int main(void)
{
    uint8_t i = 0;


    BLEBS_init();

    BlePacketEncode(blePacket1, sizeof(blePacket1), 37);
    BlePacketEncode(blePacket2, sizeof(blePacket2), 38);

    //flip bit
    for(i=0; i<sizeof(blePacket2); i++)
    {
        blePacket2[i] = ~blePacket2[i];
    }
    while(1)
    {
        gpioSendBle();
        //timerSendBle();
    }
	return 0;
}

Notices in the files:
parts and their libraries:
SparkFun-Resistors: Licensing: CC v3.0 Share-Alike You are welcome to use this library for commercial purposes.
